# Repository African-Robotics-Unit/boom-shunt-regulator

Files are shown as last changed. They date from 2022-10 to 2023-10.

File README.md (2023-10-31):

# Shunt Regulator

![Build with PlatformIO](https://img.shields.io/badge/build%20with-PlatformIO-orange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)

Schematic and firmware for a very simple shunt regulator based on the [ODrive](https://odriverobotics.com) one. This shunt regulator was designed to be used with a 24V or 48V supply powering brushless motors. When doing negative work the motors will back-feed the power supply, raising the voltage and potentially triggering the over voltage protection. The shunt regulator will detect this rise in voltage and dissipate power through a power resistor, essentially acting as a variable load and regulating the voltage.

## Schematic
<p align="center">
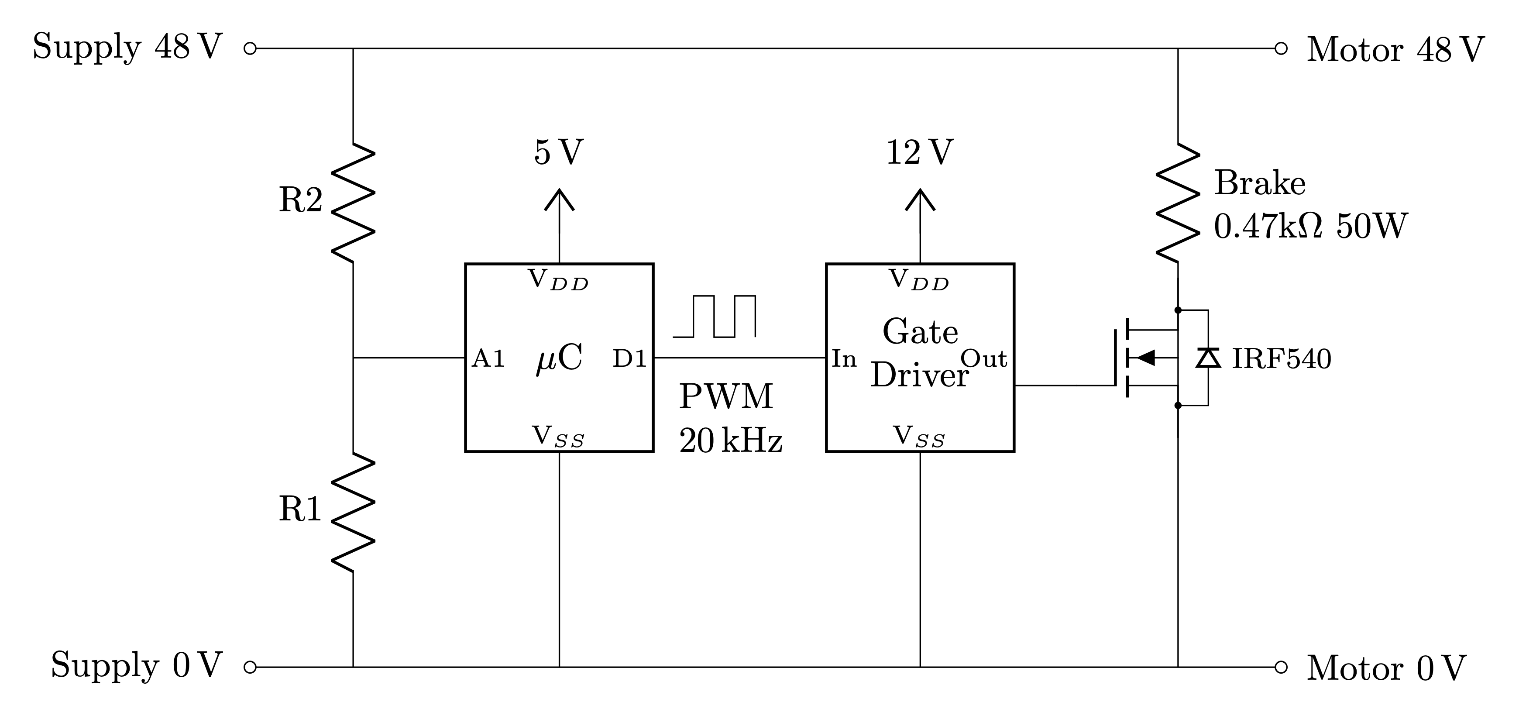
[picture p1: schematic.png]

</p>

The amount of power dissipated in the brake resistor is controlled via the 20kHz PWM signal going to the MOSFET driver. The duty cycle is ramped up from 0% for any voltages above `overvoltage_ramp_start` and maxes out at 100% for voltages at or above `overvoltage_ramp_end`. This provides a smoother fade in or out, as opposed to suddenly dumping the maximum possible power through the resistor.

`overvoltage_ramp_start` and `overvoltage_ramp_end` must be set in the firmware based on the power supply voltage. 
These are measured by a 1/20 voltage divider (not 100% accurate due to resistor tolerances).
`overvoltage_ramp_start` should be at least 2V to 4V above the power supply voltage. Setting this value too close or below the power supply voltage will result in a fried MOSFET or brake resistor. If the resistor gets warm without the motors braking, increase this value. Set `overvoltage_ramp_end` to a value which is below the power supplies overvoltage protection and the motor's maximum rated voltage, but not too close to `overvoltage_ramp_start`.

The circuit in the lab has a maximum rated voltage of 65V.
It has been altered from its original design to use an Arduino Nano 33 IoT.

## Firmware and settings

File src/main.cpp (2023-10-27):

#include <Arduino.h>
#include <SAMD21turboPWM.h>

// const int ledPin = 13;
const int brake_enable_pin = 5;
const int bus_voltage_pin = A6;
const float overvoltage_ramp_start = 28.0f; // NB: must be above supply voltage
const float overvoltage_ramp_end = 36.0f;
TurboPWM pwm;

float brake_duty = 0.0f;
float bus_voltage = 0.0f;
int output_duty = 1000;

void setup() {
  pinMode(LED_BUILTIN, OUTPUT);
  // pinMode(brake_enable_pin, OUTPUT);
  // pinMode(10, OUTPUT);
  pinMode(bus_voltage_pin, INPUT);

  pwm.setClockDivider(20 , false); // set clock to 188kHz;
  pwm.timer(0, 256, 8, false);
  pwm.enable(0, true);
  // pwm.analogWrite(brake_enable_pin, output_duty);
  analogReadResolution(12);
  Serial.begin(115200);
  // digitalWrite(LED_BUILTIN, HIGH); // ready
  analogWrite(10, 128);
  
}

void loop() {
  bus_voltage = map((float)analogRead(bus_voltage_pin), 0, 4095, 0.0f, float(3.3*21)) ;
  // Serial.println(analogRead(bus_voltage_pin));
  
  Serial.println(pwm.frequency(0));
  brake_duty = min(max((bus_voltage - overvoltage_ramp_start)/(overvoltage_ramp_end - overvoltage_ramp_start), 0.0f), 1.0f);
  output_duty = (int)(1000*(1-brake_duty));
  // pwm.analogWrite(brake_enable_pin, 1000);
  // Serial.println(output_duty);
  // delay(100);
  pwm.analogWrite(brake_enable_pin, output_duty); // MOSFET on when low
  if ((brake_duty)>0){
    digitalWrite(LED_BUILTIN, HIGH);
  } else {
    digitalWrite(LED_BUILTIN, LOW);
  }
}

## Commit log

2022-10-28 Add schematic
2023-10-25 Change circuit to Arduino Nano 33 IoT and update code accordingly
2023-10-27 Change uC to Arduino Nano 33 IoT
    Update code according to new pinout
2026-01-19 Unknown (whoops)
    [BoomShuntRegulator.kicad_pcb, BoomShuntRegulator.kicad_sch]
